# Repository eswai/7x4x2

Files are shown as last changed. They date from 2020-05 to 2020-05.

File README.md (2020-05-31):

# 7x4x2 - wireless split ortholinear keyboard

7x4x2 (seven-four-two)はBluetooth対応の左右分割式、格子配列のキーボードです。
本キーボードはSatT氏が設計されたCaravelleの公開情報を活用させていただき、主にキーの配列を変更したものです。
SatT氏のご厚意に感謝いたします。

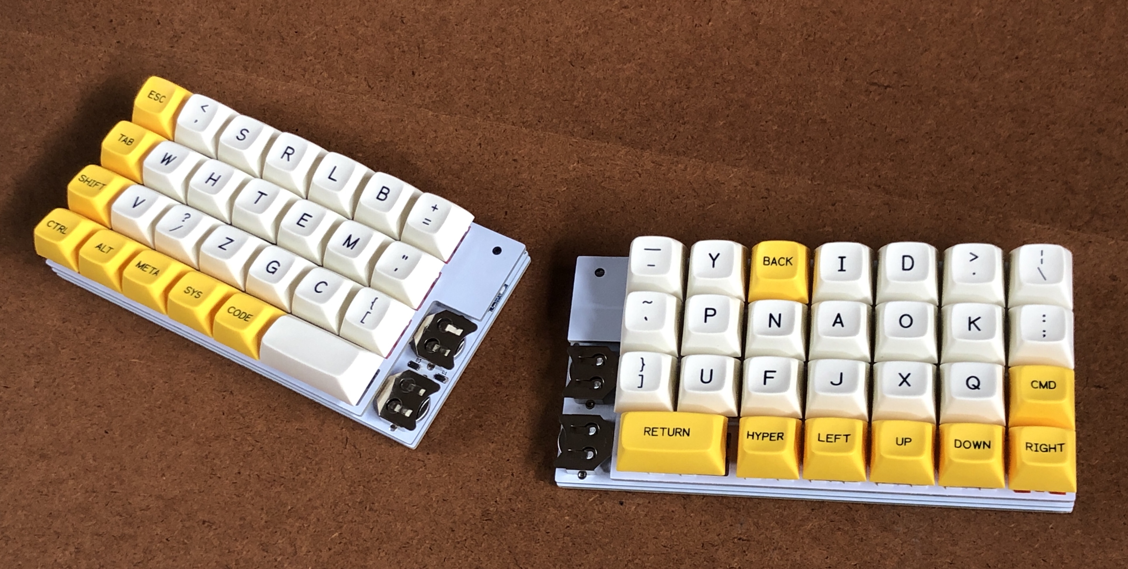
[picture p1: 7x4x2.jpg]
7x4x2


## 必要な部品

- タカチ電機工業 BK型コイン電池ホルダー BK-869
- 電池 CR1632
- マイコン Laird BL652-SA-01-T/R 
- チップ積層セラミックコンデンサー 100μF6.3V X6R 3216
- チップ積層セラミックコンデンサー 0.1μF50V F 2012
- 表面実装用ショットキーバリアダイオード (40V2A)SS2040FL
- 小型スライドスイッチ 1回路2接点(面実装タイプ)  SSW1P2T-SMT
- アルプス電気 (ALPS) 表面実装タクトスイッチ 5.2mm角薄型タイプ SKQGAFE010
- スタンドオフ M2 6.5mm ARB-2006.5E　
- ネジ M2x5mm
- Cherry MXスイッチ
- MXスイッチ用ソケット

## ファームウェア

1. ST-LinkとopenOCDを使用してcaravelleのブートローダーを書き込む
2. QMKファームウェアをコンパイルする https://github.com/eswai/qmk_ble/tree/nrf52/keyboards/eswai/7x4x2
3. nRF toolboxを使用して、ファームウェアを書き込む

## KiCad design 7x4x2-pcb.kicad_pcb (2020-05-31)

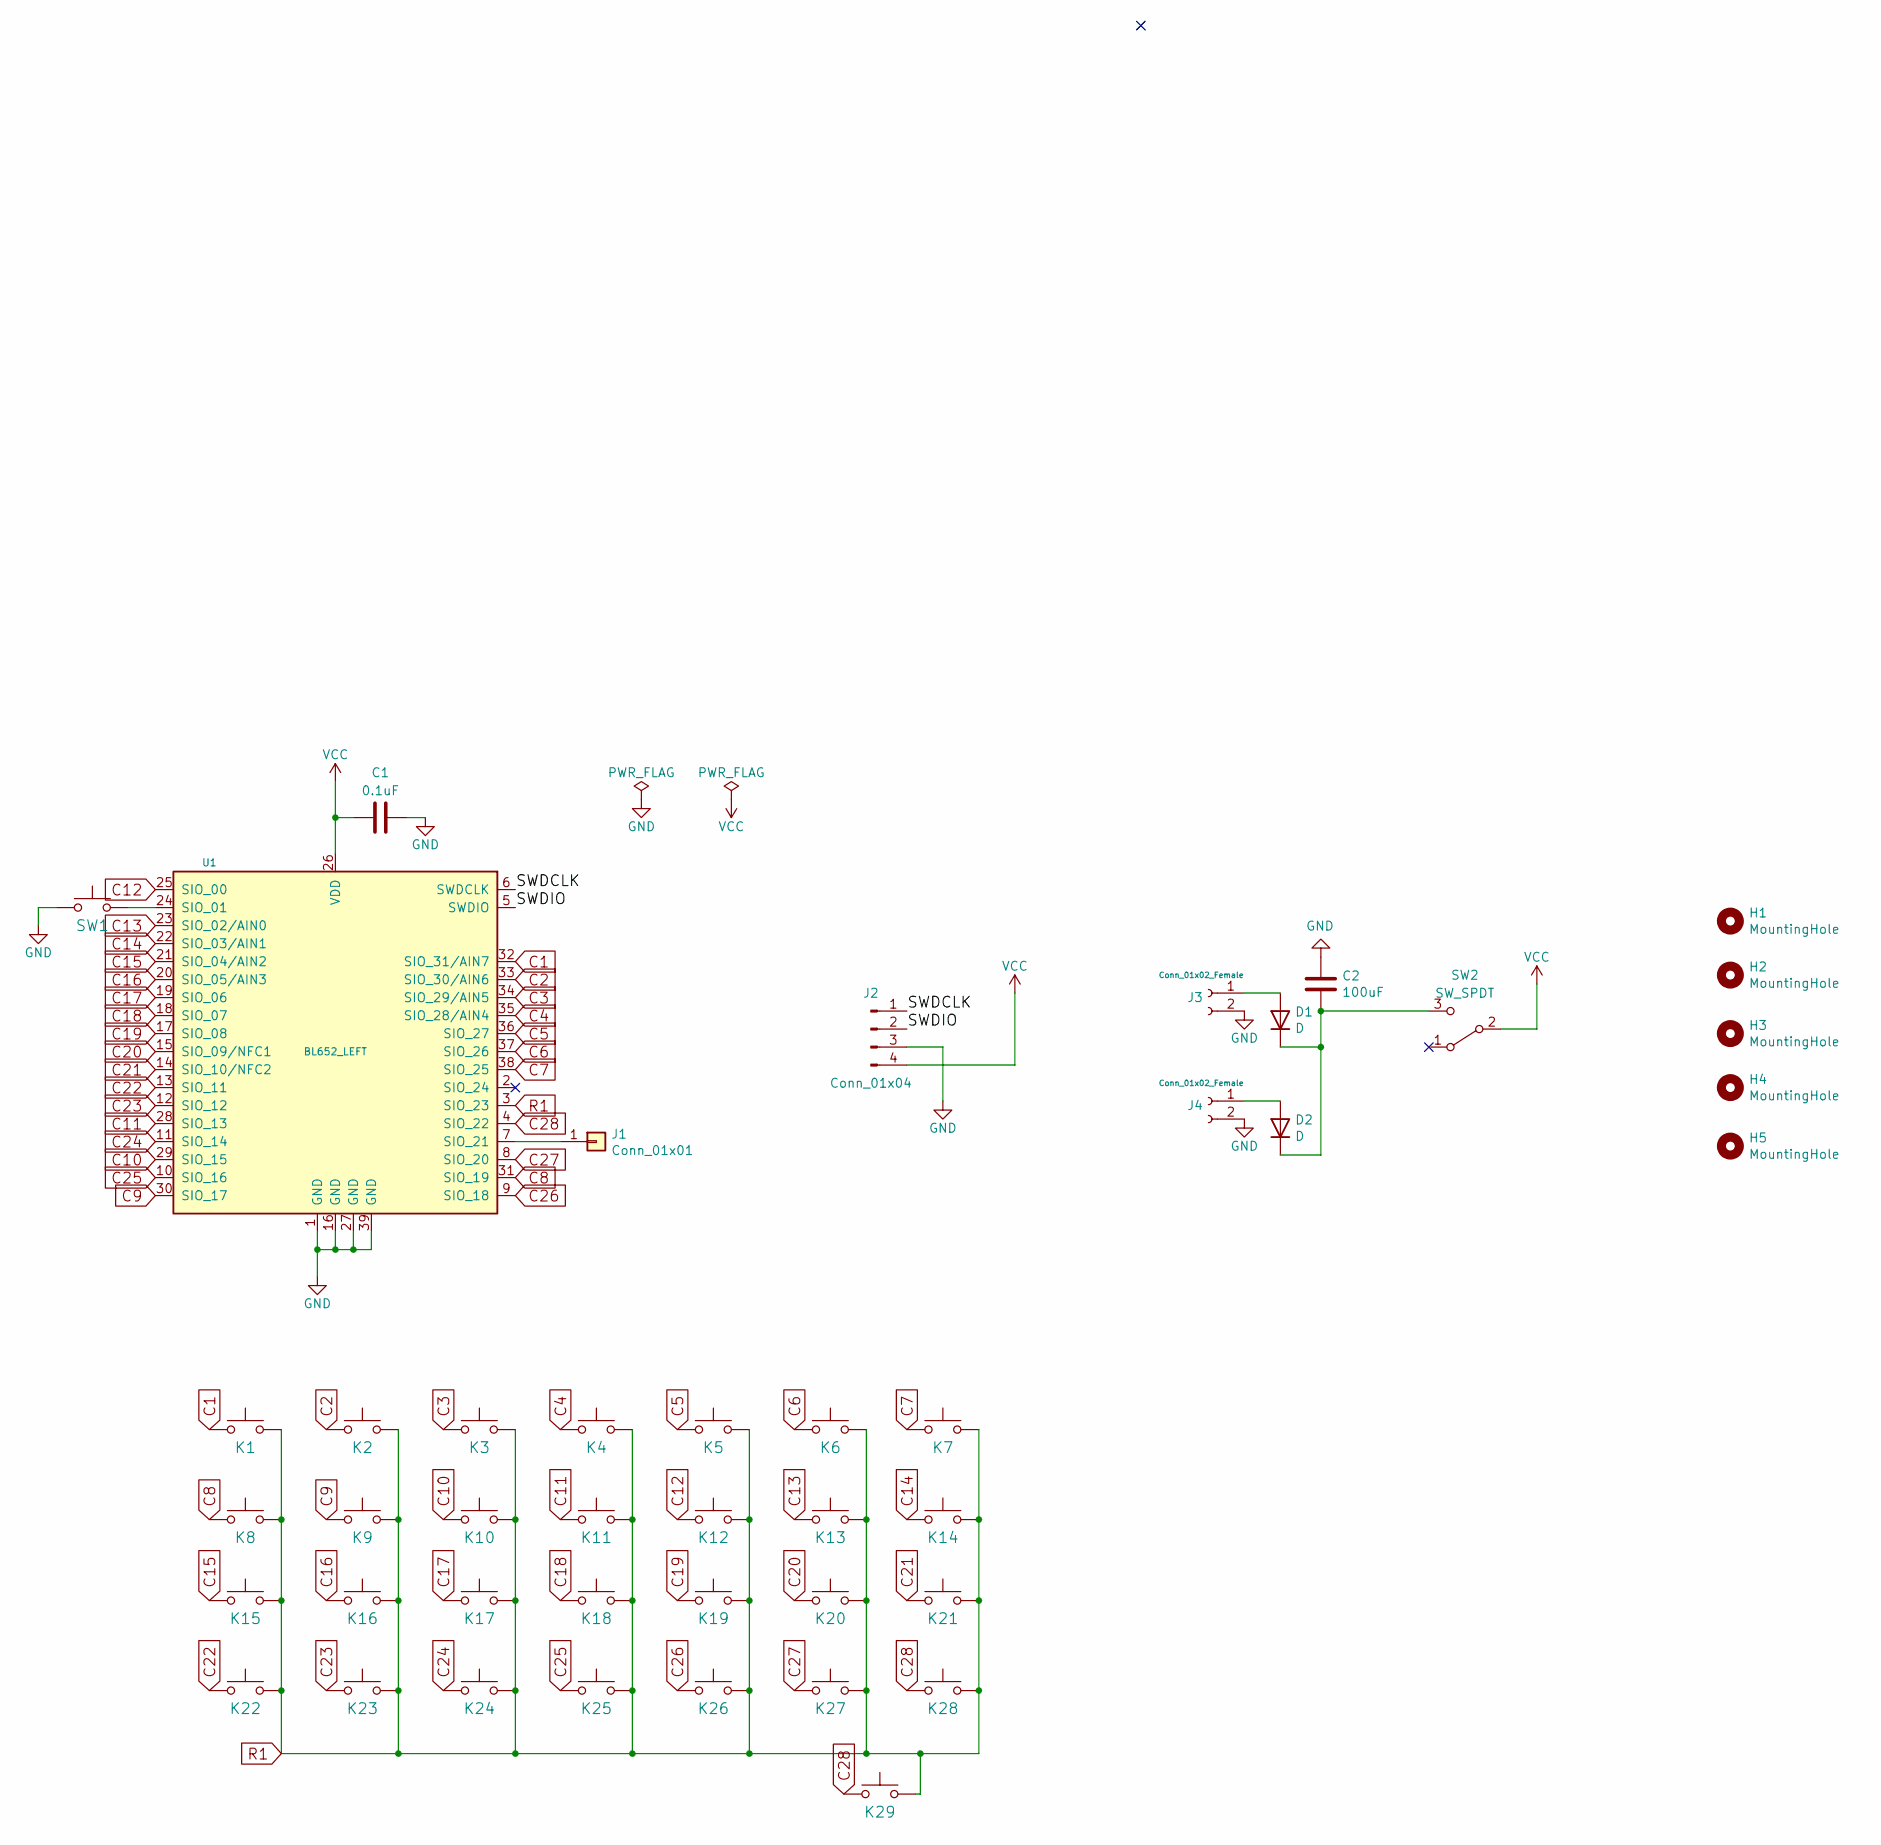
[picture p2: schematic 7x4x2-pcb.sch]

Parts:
C1: 0.1uF; C_0603_1608Metric_Pad1.05x0.95mm_HandSolder
C2: 100uF; C_1206_3216Metric_Pad1.42x1.75mm_HandSolder
D1, D2: D; D_SOD-123
H1, H2, H3, H4, H5: MountingHole; MountingHole_4.3mm_M4
J1: Conn_01x01; breakout-pad
J2: Conn_01x04; programming_port
J3, J4: Conn_01x02_Female; BK-869
K1, K2, K3, K4, K5, K6, K7, K8, K9, K10, K11, K12, K13, K14, K15, K16, K17, K18, K19, K20, K21, K22, K23, K24, K25, K26, K27, K28, K29: keyboard_parts_KEYSW; CherryMX_Hotswap
SW1: RESET_SW; SW_SPST_SKQG_WithoutStem
SW2: SW_SPDT; 679-1847-1-ND‎
U1: BL652_LEFT; Laird_BL652_Hand

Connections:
/SWDCLK: J2.1, U1.6 (SWDCLK)
/SWDIO: J2.2, U1.5 (SWDIO)
C1: K1.1, U1.32 (SIO_31/AIN7)
C2: K2.1, U1.33 (SIO_30/AIN6)
C3: K3.1, U1.34 (SIO_29/AIN5)
C4: K4.1, U1.35 (SIO_28/AIN4)
C5: K5.1, U1.36 (SIO_27)
C6: K6.1, U1.37 (SIO_26)
C7: K7.1, U1.38 (SIO_25)
C8: K8.1, U1.31 (SIO_19)
C9: K9.1, U1.30 (SIO_17)
C10: K10.1, U1.29 (SIO_15)
C11: K11.1, U1.28 (SIO_13)
C12: K12.1, U1.25 (SIO_00)
C13: K13.1, U1.23 (SIO_02/AIN0)
C14: K14.1, U1.22 (SIO_03/AIN1)
C15: K15.1, U1.21 (SIO_04/AIN2)
C16: K16.1, U1.20 (SIO_05/AIN3)
C17: K17.1, U1.19 (SIO_06)
C18: K18.1, U1.18 (SIO_07)
C19: K19.1, U1.17 (SIO_08)
C20: K20.1, U1.15 (SIO_09/NFC1)
C21: K21.1, U1.14 (SIO_10/NFC2)
C22: K22.1, U1.13 (SIO_11)
C23: K23.1, U1.12 (SIO_12)
C24: K24.1, U1.11 (SIO_14)
C25: K25.1, U1.10 (SIO_16)
C26: K26.1, U1.9 (SIO_18)
C27: K27.1, U1.8 (SIO_20)
C28: K28.1, K29.1, U1.4 (SIO_22)
GND: C1.2, C2.1, J2.3, J3.2, J4.2, SW1.1, U1.1 (GND), U1.16 (GND), U1.27 (GND), U1.39 (GND)
unnamed: C2.2, D1.1 (K), D2.1 (K), SW2.3 (C)
unnamed: D1.2 (A), J3.1
unnamed: D2.2 (A), J4.1
unnamed: J1.1, U1.7 (SIO_21)
unnamed: SW1.2, U1.24 (SIO_01)
R1: K1.2, K2.2, K3.2, K4.2, K5.2, K6.2, K7.2, K8.2, K9.2, K10.2, K11.2, K12.2, K13.2, K14.2, K15.2, K16.2, K17.2, K18.2, K19.2, K20.2, K21.2, K22.2, K23.2, K24.2, K25.2, K26.2, K27.2, K28.2, K29.2, U1.3 (SIO_23)
VCC: C1.1, J2.4, SW2.2 (B), U1.26 (VDD)

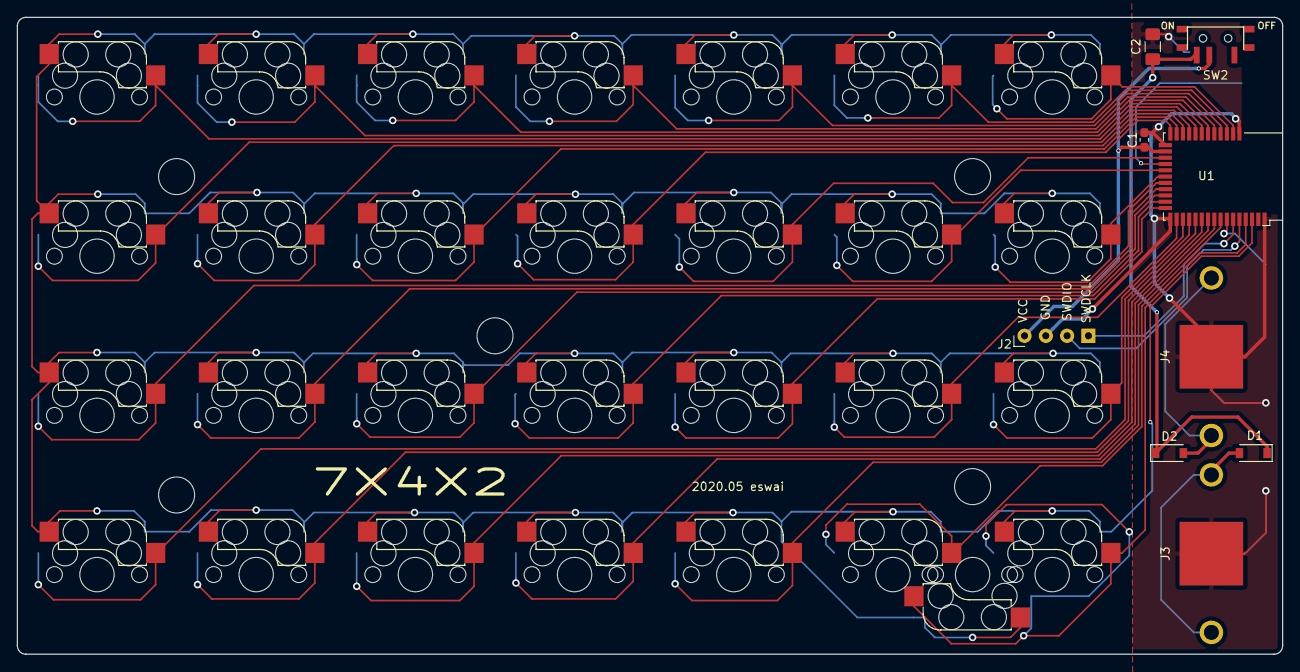
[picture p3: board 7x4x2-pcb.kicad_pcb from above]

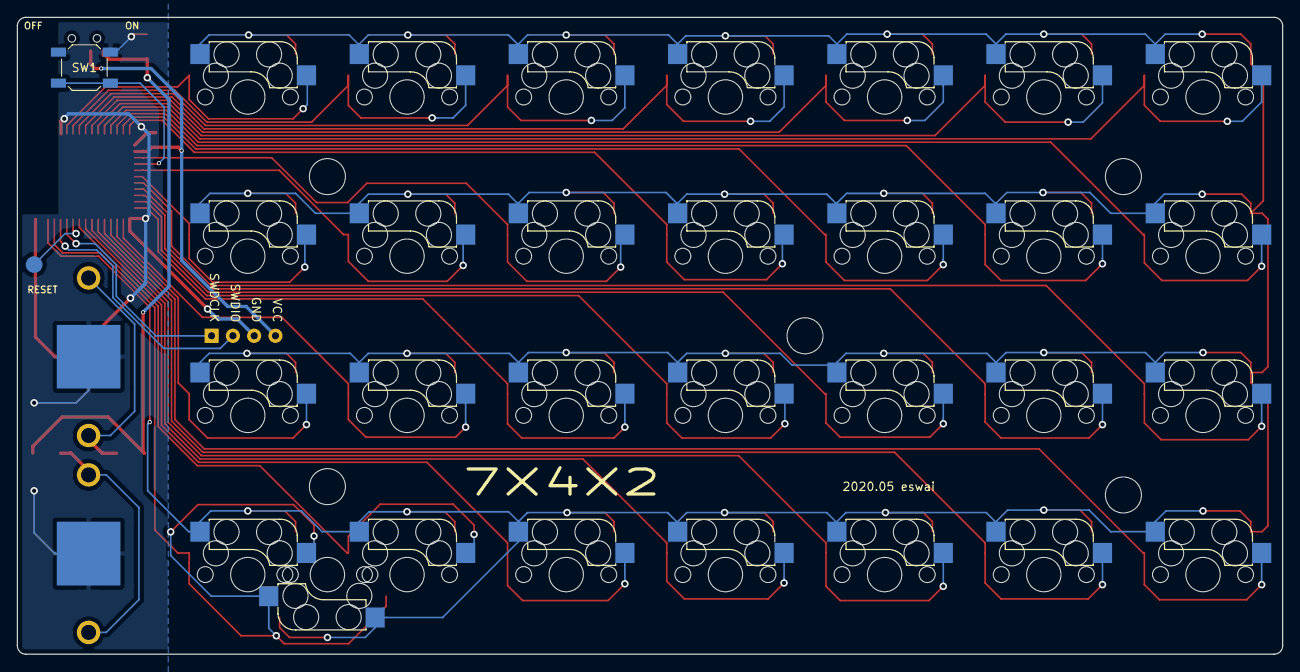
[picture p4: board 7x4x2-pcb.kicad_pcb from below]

Board: 2 copper layers, 151.0 x 76.0 mm, 45 parts (2 on the bottom side), 38 nets.

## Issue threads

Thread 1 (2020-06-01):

Could not find SS2040FL on pcb

BenRoe, 2020-06-01:
Hello,
thanks for this open source bl board.
I checked the mid pcb and could not find the (40V2A)SS2040FL, but it's mentioned in the bom.

eswai, 2020-06-01:
They are located as D1 and D2 between two battery holders.

BenRoe, 2020-06-01:
My bad, thought these are normal diodes.
Btw do already tested the pcb?

BenRoe, 2020-06-01:
I also get a "Audit fail" at jlcpcb, because "the spacing between slot to slot or outline require 3mm at least in case of break off , kindly replace with new file ."
I never had a problem with that, but since one week i get this error.

eswai, 2020-06-01:
JLCPCB actually produced the PCB for me two weeks ago without any issues. The keyboard works fine.

Closed 2020-06-02.
